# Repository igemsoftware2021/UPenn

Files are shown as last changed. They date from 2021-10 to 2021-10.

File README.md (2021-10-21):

# UPenn

OptoReader repository for software package to run the OptoReader, hardware files, and modeling scripts.

## Running the OptoReader

The OptoReader can be run using a computer and two Arduino Micros with the following provided code files: 

*OptoPlate_topArduino.ino* - Arduino code to control the stimulation plate. Takes in experiment stimulation settings, controls the 96 stimulation and optical density LEDs, and communicates with the reading plate for optical density measurements.

*PlateReader_bottomArduino.ino* - Arduino code to control the reading plate. Takes in experiment reading settings, controls the 96 excitation LEDs and photosensors, and communicates with the stimulation plate for optical density measurements. 

*OptoReader_Protocol.py* - Python code to take in inputs from the graphical user interface, keep track of experiment timing, and communicate with Arduinos to initiate readings and calibrate the optical density LEDs.

*GUI.py* - Python code creating a graphical user interface to take in user experiment inputs including stimulation settings, reading settings, feedback control, and experiment timing.

To run the OptoReader, first upload OptoPlate_topArduino.ino to the stimulation (top) plate Arduino and upload *PlateReader_bottomArduino.ino* to the reading (bottom) Arduino. Note the port name for each Arduino. If necessary, rename the port name from the preset COM11 and COM12 in *OptoReader_Protocol.py*. Finally, run GUI.py to open the graphical user interface and enter your experiment settings. Ensure that the image files *blue_logo.png* and *optologo_small.png* and the Python file *OptoReader_Protocol.py* are saved in the same folder as *GUI.py*.

## Hardware

### 3D Printed Parts
Includes files for our 3D-printed parts *Bottom_Adaptor.stl* and *Top_Adaptor.stl*. These files include the 3D model of the top adaptor and bottom adaptor, that fit each pcb board to a microwell plate.

### PCBs
Includes schematic files for our printed circuit boards (PCBs) *PlateReader.kicad_pcb* and *optoPlate96.kicad_pcb*. These can be sent directly to a company that provides printed circuit boards. The board components are soldered directly onto the boards. 

## Fluorescence Calibration Modeling

Files for our fluorescence calibration modeling include *FirstFit.m* and *Fluorescence_Calibration_Curve.m*. These files use our device’s fluorescence readings at different known concentrations to fit each well to a fluorescent calibration curve.

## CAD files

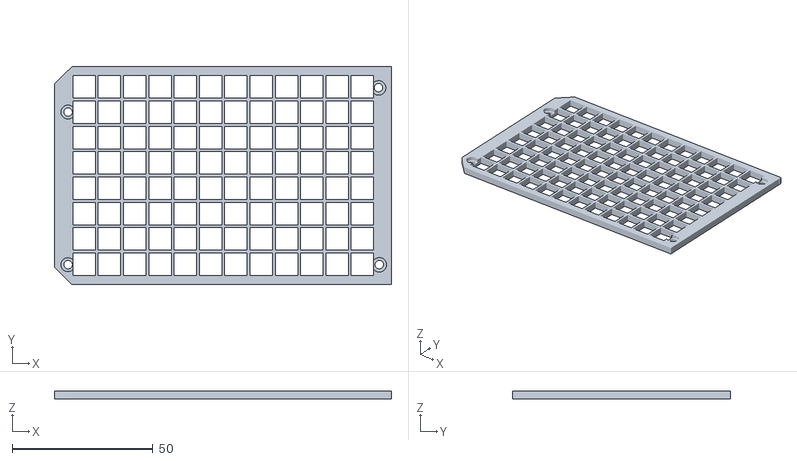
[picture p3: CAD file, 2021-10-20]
3D_Printed_Parts/Bottom_Adaptor.stl
119.9 x 77.6 x 3.00

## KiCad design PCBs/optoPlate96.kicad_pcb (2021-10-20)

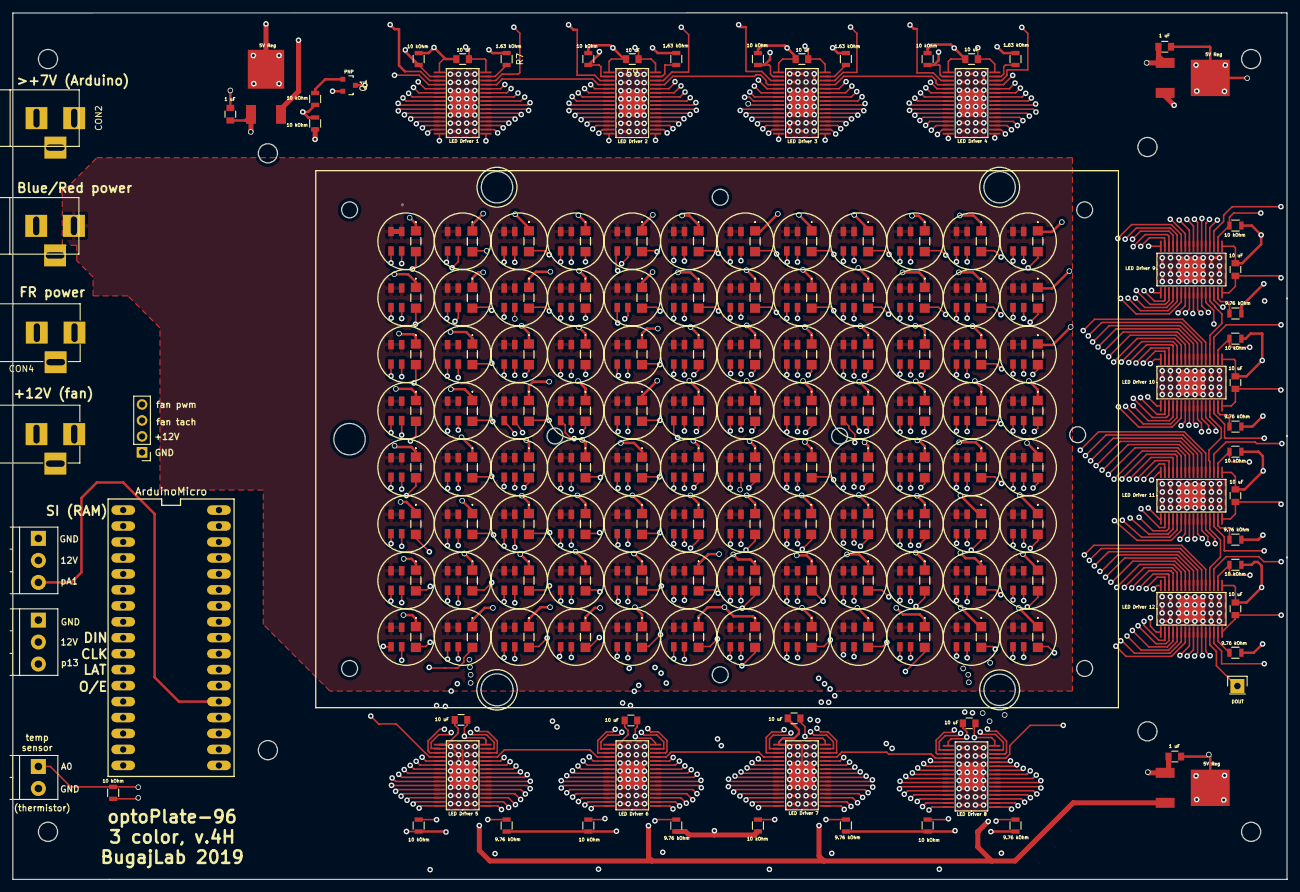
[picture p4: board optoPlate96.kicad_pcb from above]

Board: 6 copper layers, 202.8 x 137.9 mm, 260 parts (0 on the bottom side), 332 nets.

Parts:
C7, C8, C9, C10, C11, C12, C13, C14, C15, C16, C17, C18, C19, C25, C27: C; C_0805
CON1, CON2, CON3, CON4: BARREL_JACK
D3, D5, D7, D9, D11, D13, D15, D17, D19, D21, D23, D25, D27, D29, D31, D33, D35, D37, D39, D41, D43, D45, D47, D49, D51, D53, D55, D57, D59, D61, D63, D65, D67, D69, D71, D73, D75, D77, D79, D81, D83, D85, D87, D89, D91, D93, D95, D97, D99, D101, D103, D105, D107, D109, D111, D113, D115, D117, D119, D121, D123, D125, D127, D129, D131, D133, D135, D137, D139, D141, D143, D145, D147, D149, D151, D153, D155, D157, D159, D161, D163, D165, D167, D169, D171, D173, D175, D177, D179, D181, D183, D185, D187, D189, D191, D193: LED; HSMCC380
D4, D6, D8, D10, D12, D14, D16, D18, D20, D22, D24, D26, D28, D30, D32, D34, D36, D38, D40, D42, D44, D46, D48, D50, D52, D54, D56, D58, D60, D62, D64, D66, D68, D70, D72, D74, D76, D78, D80, D82, D84, D86, D88, D90, D92, D94, D96, D98, D100, D102, D104, D106, D108, D110, D112, D114, D116, D118, D120, D122, D124, D126, D128, D130, D132, D134, D136, D138, D140, D142, D144, D146, D148, D150, D152, D154, D156, D158, D160, D162, D164, D166, D168, D170, D172, D174, D176, D178, D180, D182, D184, D186, D188, D190, D192, D194: BI_LED; BiLED3528RedBlue
P2: CONN_01X01; Pin_Header_Straight_1x01
P3, P6: CONN_01X03; TerminalBlock_Pheonix_PT-3.5mm_3pol
P4: CONN_01X04; Pin_Header_Straight_1x04_Pitch2.54mm
P5: CONN_01X02; TerminalBlock_Pheonix_PT-3.5mm_2pol
Q1: PNP; PNP_SOT-23_correct
R1, R2, R3, R6, R7, R8, R9, R10, R11, R12, R13, R14, R15, R16, R17, R18, R19, R20, R21, R22, R23, R24, R25, R26, R27, R28, R29: R; R_0805
U1: ArduinoMicro; ArduinoMicro_DIP34
U4, U17, U18: LM2931AZ-5.0; Voltage_Regulator_LM2931ADT-5.0_noHoles
U5, U6, U7, U8, U9, U10, U11, U12, U13, U14, U15, U16: TLC5947; TLC5947_noHoles

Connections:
/3.3V: CON1.1, D4.1, D4.2, D6.1, D6.2, D8.1, D8.2, D10.1, D10.2, D12.1, D12.2, D14.1, D14.2, D16.1, D16.2, D18.1, D18.2, D20.1, D20.2, D22.1, D22.2, D24.1, D24.2, D26.1, D26.2, D28.1, D28.2, D30.1, D30.2, D32.1, D32.2, D34.1, D34.2, D36.1, D36.2, D38.1, D38.2, D40.1, D40.2, D42.1, D42.2, D44.1, D44.2, D46.1, D46.2, D48.1, D48.2, D50.1, D50.2, D52.1, D52.2, D54.1, D54.2, D56.1, D56.2, D58.1, D58.2, D60.1, D60.2, D62.1, D62.2, D64.1, D64.2, D66.1, D66.2, D68.1, D68.2, D70.1, D70.2, D72.1, D72.2, D74.1, D74.2, D76.1, D76.2, D78.1, D78.2, D80.1, D80.2, D82.1, D82.2, D84.1, D84.2, D86.1, D86.2, D88.1, D88.2, D90.1, D90.2, D92.1, D92.2, D94.1, D94.2, D96.1, D96.2, D98.1, D98.2, D100.1, D100.2, D102.1, D102.2, D104.1, D104.2, D106.1, D106.2, D108.1, D108.2, D110.1, D110.2, D112.1, D112.2, D114.1, D114.2, D116.1, D116.2, D118.1, D118.2, D120.1, D120.2, D122.1, D122.2, D124.1, D124.2, D126.1, D126.2, D128.1, D128.2, D130.1, D130.2, D132.1, D132.2, D134.1, D134.2, D136.1, D136.2, D138.1, D138.2, D140.1, D140.2, D142.1, D142.2, D144.1, D144.2, D146.1, D146.2, D148.1, D148.2, D150.1, D150.2, D152.1, D152.2, D154.1, D154.2, D156.1, D156.2, D158.1, D158.2, D160.1, D160.2, D162.1, D162.2, D164.1, D164.2, D166.1, D166.2, D168.1, D168.2, D170.1, D170.2, D172.1, D172.2, D174.1, D174.2, D176.1, D176.2, D178.1, D178.2, D180.1, D180.2, D182.1, D182.2, D184.1, D184.2, D186.1, D186.2, D188.1, D188.2, D190.1, D190.2, D192.1, D192.2, D194.1, D194.2
/3.3Vreal: R3.2, U1.19, U1.20
/5V: C13.1, C25.1, C27.1, CON2.1, U1.32, U4.3, U17.3, U18.3
/+12V: CON3.1, P3.2, P4.2, P6.2
/B1: D4.4, U5.5
/B2: D6.4, U5.6
/B3: D8.4, U5.7
/B4: D10.4, U5.8
/B5: D12.4, U5.9
/B6: D14.4, U5.10
/B7: D16.4, U5.11
/B8: D18.4, U5.12
/B9: D20.4, U5.13
/B10: D22.4, U5.14
/B11: D24.4, U5.15
/B12: D26.4, U5.16
/B13: D28.4, U5.17
/B14: D30.4, U5.18
/B15: D32.4, U5.19
/B16: D34.4, U5.20
/B17: D36.4, U5.21
/B18: D38.4, U5.22
/B19: D40.4, U5.23
/B20: D42.4, U5.24
/B21: D44.4, U5.25
/B22: D46.4, U5.26
/B23: D48.4, U5.27
/B24: D50.4, U5.28
/B25: D52.4, U6.5
/B26: D54.4, U6.6
/B27: D56.4, U6.7
/B28: D58.4, U6.8
/B29: D60.4, U6.9
/B30: D62.4, U6.10
/B31: D64.4, U6.11
/B32: D66.4, U6.12
/B33: D68.4, U6.13
/B34: D70.4, U6.14
/B35: D72.4, U6.15
/B36: D74.4, U6.16
/B37: D76.4, U6.17
/B38: D78.4, U6.18
/B39: D80.4, U6.19
/B40: D82.4, U6.20
/B41: D84.4, U6.21
/B42: D86.4, U6.22
/B43: D88.4, U6.23
/B44: D90.4, U6.24
/B45: D92.4, U6.25
/B46: D94.4, U6.26
/B47: D96.4, U6.27
/B48: D98.4, U6.28
/B49: D100.4, U7.5
/B50: D102.4, U7.6
/B51: D104.4, U7.7
/B52: D106.4, U7.8
/B53: D108.4, U7.9
/B54: D110.4, U7.10
/B55: D112.4, U7.11
/B56: D114.4, U7.12
/B57: D116.4, U7.13
/B58: D118.4, U7.14
/B59: D120.4, U7.15
/B60: D122.4, U7.16
/B61: D124.4, U7.17
/B62: D126.4, U7.18
/B63: D128.4, U7.19
/B64: D130.4, U7.20
/B65: D132.4, U7.21
/B66: D134.4, U7.22
/B67: D136.4, U7.23
/B68: D138.4, U7.24
/B69: D140.4, U7.25
/B70: D142.4, U7.26
/B71: D144.4, U7.27
/B72: D146.4, U7.28
/B73: D148.4, U8.5
/B74: D150.4, U8.6
/B75: D152.4, U8.7
/B76: D154.4, U8.8
/B77: D156.4, U8.9
/B78: D158.4, U8.10
/B79: D160.4, U8.11
/B80: D162.4, U8.12
/B81: D164.4, U8.13
/B82: D166.4, U8.14
/B83: D168.4, U8.15
/B84: D170.4, U8.16
/B85: D172.4, U8.17
/B86: D174.4, U8.18
/B87: D176.4, U8.19
/B88: D178.4, U8.20
/B89: D180.4, U8.21
/B90: D182.4, U8.22
/B91: D184.4, U8.23
/B92: D186.4, U8.24
/B93: D188.4, U8.25
/B94: D190.4, U8.26
/B95: D192.4, U8.27
/B96: D194.4, U8.28
/BLANK: Q1.3, R6.2, R8.2, R10.2, R12.2, R14.2, R16.2, R18.2, R20.2, R22.2, R24.2, R26.2, R28.2, U5.2, U6.2, U7.2, U8.2, U9.2, U10.2, U11.2, U12.2, U13.2, U14.2, U15.2, U16.2
/CLK: U1.10, U5.3, U6.3, U7.3, U8.3, U9.3, U10.3, U11.3, U12.3, U13.3, U14.3, U15.3, U16.3
/DIN: U1.9, U5.4
/DOUT: P2.1, U16.29
/FR1: D3.2, U13.5
/FR2: D5.2, U13.17
/FR3: D7.2, U14.5
/FR4: D9.2, U14.17
/FR5: D11.2, U15.5
/FR6: D13.2, U15.17
/FR7: D15.2, U16.5
/FR8: D17.2, U16.17
/FR9: D19.2, U13.6
/FR10: D21.2, U13.18
/FR11: D23.2, U14.6
/FR12: D25.2, U14.18
/FR13: D27.2, U15.6
/FR14: D29.2, U15.18
/FR15: D31.2, U16.6
/FR16: D33.2, U16.18
/FR17: D35.2, U13.7
/FR18: D37.2, U13.19
/FR19: D39.2, U14.7
/FR20: D41.2, U14.19
/FR21: D43.2, U15.7
/FR22: D45.2, U15.19
/FR23: D47.2, U16.7
/FR24: D49.2, U16.19
/FR25: D51.2, U13.8
/FR26: D53.2, U13.20
/FR27: D55.2, U14.8
/FR28: D57.2, U14.20
/FR29: D59.2, U15.8
/FR30: D61.2, U15.20
/FR31: D63.2, U16.8
/FR32: D65.2, U16.20
/FR33: D67.2, U13.9
/FR34: D69.2, U13.21
/FR35: D71.2, U14.9
/FR36: D73.2, U14.21
/FR37: D75.2, U15.9
/FR38: D77.2, U15.21
/FR39: D79.2, U16.9
/FR40: D81.2, U16.21
/FR41: D83.2, U13.10
/FR42: D85.2, U13.22
/FR43: D87.2, U14.10
/FR44: D89.2, U14.22
/FR45: D91.2, U15.10
/FR46: D93.2, U15.22
/FR47: D95.2, U16.10
/FR48: D97.2, U16.22
/FR49: D99.2, U13.11
/FR50: D101.2, U13.23
/FR51: D103.2, U14.11
/FR52: D105.2, U14.23
/FR53: D107.2, U15.11
/FR54: D109.2, U15.23
/FR55: D111.2, U16.11
/FR56: D113.2, U16.23
/FR57: D115.2, U13.12
/FR58: D117.2, U13.24
/FR59: D119.2, U14.12
/FR60: D121.2, U14.24
/FR61: D123.2, U15.12
/FR62: D125.2, U15.24
/FR63: D127.2, U16.12
/FR64: D129.2, U16.24
/FR65: D131.2, U13.13
/FR66: D133.2, U13.25
/FR67: D135.2, U14.13
/FR68: D137.2, U14.25
/FR69: D139.2, U15.13
/FR70: D141.2, U15.25
/FR71: D143.2, U16.13
/FR72: D145.2, U16.25
/FR73: D147.2, U13.14
/FR74: D149.2, U13.26
/FR75: D151.2, U14.14
/FR76: D153.2, U14.26
/FR77: D155.2, U15.14
/FR78: D157.2, U15.26
/FR79: D159.2, U16.14
/FR80: D161.2, U16.26
/FR81: D163.2, U13.15
/FR82: D165.2, U13.27
/FR83: D167.2, U14.15
/FR84: D169.2, U14.27
/FR85: D171.2, U15.15
/FR86: D173.2, U15.27
/FR87: D175.2, U16.15
/FR88: D177.2, U16.27
/FR89: D179.2, U13.16
/FR90: D181.2, U13.28
/FR91: D183.2, U14.16
/FR92: D185.2, U14.28
/FR93: D187.2, U15.16
/FR94: D189.2, U15.28
/FR95: D191.2, U16.16
/FR96: D193.2, U16.28
/LAT: U1.11, U5.30, U6.30, U7.30, U8.30, U9.30, U10.30, U11.30, U12.30, U13.30, U14.30, U15.30, U16.30
/R1: D4.3, U9.5
/R2: D6.3, U9.6
/R3: D8.3, U9.7
/R4: D10.3, U9.8
/R5: D12.3, U9.9
/R6: D14.3, U9.10
/R7: D16.3, U9.11
/R8: D18.3, U9.12
/R9: D20.3, U9.13
/R10: D22.3, U9.14
/R11: D24.3, U9.15
/R12: D26.3, U9.16
/R13: D28.3, U9.17
/R14: D30.3, U9.18
/R15: D32.3, U9.19
/R16: D34.3, U9.20
/R17: D36.3, U9.21
/R18: D38.3, U9.22
/R19: D40.3, U9.23
/R20: D42.3, U9.24
/R21: D44.3, U9.25
/R22: D46.3, U9.26
/R23: D48.3, U9.27
/R24: D50.3, U9.28
/R25: D52.3, U10.5
/R26: D54.3, U10.6
/R27: D56.3, U10.7
/R28: D58.3, U10.8
/R29: D60.3, U10.9
/R30: D62.3, U10.10
/R31: D64.3, U10.11
/R32: D66.3, U10.12
/R33: D68.3, U10.13
/R34: D70.3, U10.14
/R35: D72.3, U10.15
/R36: D74.3, U10.16
/R37: D76.3, U10.17
/R38: D78.3, U10.18
/R39: D80.3, U10.19
/R40: D82.3, U10.20
/R41: D84.3, U10.21
/R42: D86.3, U10.22
/R43: D88.3, U10.23
/R44: D90.3, U10.24
/R45: D92.3, U10.25
/R46: D94.3, U10.26
/R47: D96.3, U10.27
/R48: D98.3, U10.28
/R49: D100.3, U11.5
/R50: D102.3, U11.6
/R51: D104.3, U11.7
/R52: D106.3, U11.8
/R53: D108.3, U11.9
/R54: D110.3, U11.10
/R55: D112.3, U11.11
/R56: D114.3, U11.12
/R57: D116.3, U11.13
/R58: D118.3, U11.14
/R59: D120.3, U11.15
/R60: D122.3, U11.16
/R61: D124.3, U11.17
/R62: D126.3, U11.18
/R63: D128.3, U11.19
/R64: D130.3, U11.20
/R65: D132.3, U11.21
/R66: D134.3, U11.22
/R67: D136.3, U11.23
/R68: D138.3, U11.24
/R69: D140.3, U11.25
/R70: D142.3, U11.26
/R71: D144.3, U11.27
/R72: D146.3, U11.28
/R73: D148.3, U12.5
/R74: D150.3, U12.6
/R75: D152.3, U12.7
/R76: D154.3, U12.8
/R77: D156.3, U12.9
/R78: D158.3, U12.10
/R79: D160.3, U12.11
/R80: D162.3, U12.12
/R81: D164.3, U12.13
/R82: D166.3, U12.14
/R83: D168.3, U12.15
/R84: D170.3, U12.16
/R85: D172.3, U12.17
/R86: D174.3, U12.18
/R87: D176.3, U12.19
/R88: D178.3, U12.20
/R89: D180.3, U12.21
/R90: D182.3, U12.22
/R91: D184.3, U12.23
/R92: D186.3, U12.24
/R93: D188.3, U12.25
/R94: D190.3, U12.26
/R95: D192.3, U12.27
/R96: D194.3, U12.28
/Vfr: CON4.1, D3.1, D5.1, D7.1, D9.1, D11.1, D13.1, D15.1, D17.1, D19.1, D21.1, D23.1, D25.1, D27.1, D29.1, D31.1, D33.1, D35.1, D37.1, D39.1, D41.1, D43.1, D45.1, D47.1, D49.1, D51.1, D53.1, D55.1, D57.1, D59.1, D61.1, D63.1, D65.1, D67.1, D69.1, D71.1, D73.1, D75.1, D77.1, D79.1, D81.1, D83.1, D85.1, D87.1, D89.1, D91.1, D93.1, D95.1, D97.1, D99.1, D101.1, D103.1, D105.1, D107.1, D109.1, D111.1, D113.1, D115.1, D117.1, D119.1, D121.1, D123.1, D125.1, D127.1, D129.1, D131.1, D133.1, D135.1, D137.1, D139.1, D141.1, D143.1, D145.1, D147.1, D149.1, D151.1, D153.1, D155.1, D157.1, D159.1, D161.1, D163.1, D165.1, D167.1, D169.1, D171.1, D173.1, D175.1, D177.1, D179.1, D181.1, D183.1, D185.1, D187.1, D189.1, D191.1, D193.1
/aux_pwm1: P3.3, U1.18
/aux_pwm2: P6.3, U1.22
/fan_pwm: P4.4, U1.16
/fan_sense: P4.3, U1.15
/tempSense: P5.1, R3.1, U1.21
GND: C7.2, C8.2, C9.2, C10.2, C11.2, C12.2, C13.2, C14.2, C15.2, C16.2, C17.2, C18.2, C19.2, C25.2, C27.2, CON1.2, CON1.3, CON2.2, CON2.3, CON3.2, CON3.3, CON4.2, CON4.3, P3.1, P4.1, P5.2, P6.1, R1.1, R6.1, R7.1, R8.1, R9.1, R10.1, R11.1, R12.1, R13.1, R14.1, R15.1, R16.1, R17.1, R18.1, R19.1, R20.1, R21.1, R22.1, R23.1, R24.1, R25.1, R26.1, R27.1, R28.1, R29.1, U1.6, U1.31, U4.2, U5.1, U6.1, U7.1, U8.1, U9.1, U10.1, U11.1, U12.1, U13.1, U14.1, U15.1, U16.1, U17.2, U18.2
unnamed: C7.1, C10.1, C15.1, C16.1, U9.32, U10.32, U11.32, U12.32, U18.1
unnamed: C8.1, C9.1, C11.1, C12.1, Q1.1, U4.1, U5.32, U6.32, U7.32, U8.32
unnamed: C14.1, C17.1, C18.1, C19.1, U13.32, U14.32, U15.32, U16.32, U17.1
unnamed: Q1.2, R2.2
unnamed: R1.2, R2.1, U1.12
unnamed: R7.2, U5.31
unnamed: R9.2, U6.31
unnamed: R11.2, U7.31
unnamed: R13.2, U8.31
unnamed: R15.2, U9.31
unnamed: R17.2, U10.31
unnamed: R19.2, U11.31
unnamed: R21.2, U12.31
unnamed: R23.2, U13.31
unnamed: R25.2, U14.31
unnamed: R27.2, U15.31
unnamed: R29.2, U16.31
unnamed: U5.29, U6.4
unnamed: U6.29, U7.4
unnamed: U7.29, U8.4
unnamed: U8.29, U9.4
unnamed: U9.29, U10.4
unnamed: U10.29, U11.4
unnamed: U11.29, U12.4
unnamed: U12.29, U13.4
unnamed: U13.29, U14.4
unnamed: U14.29, U15.4
unnamed: U15.29, U16.4

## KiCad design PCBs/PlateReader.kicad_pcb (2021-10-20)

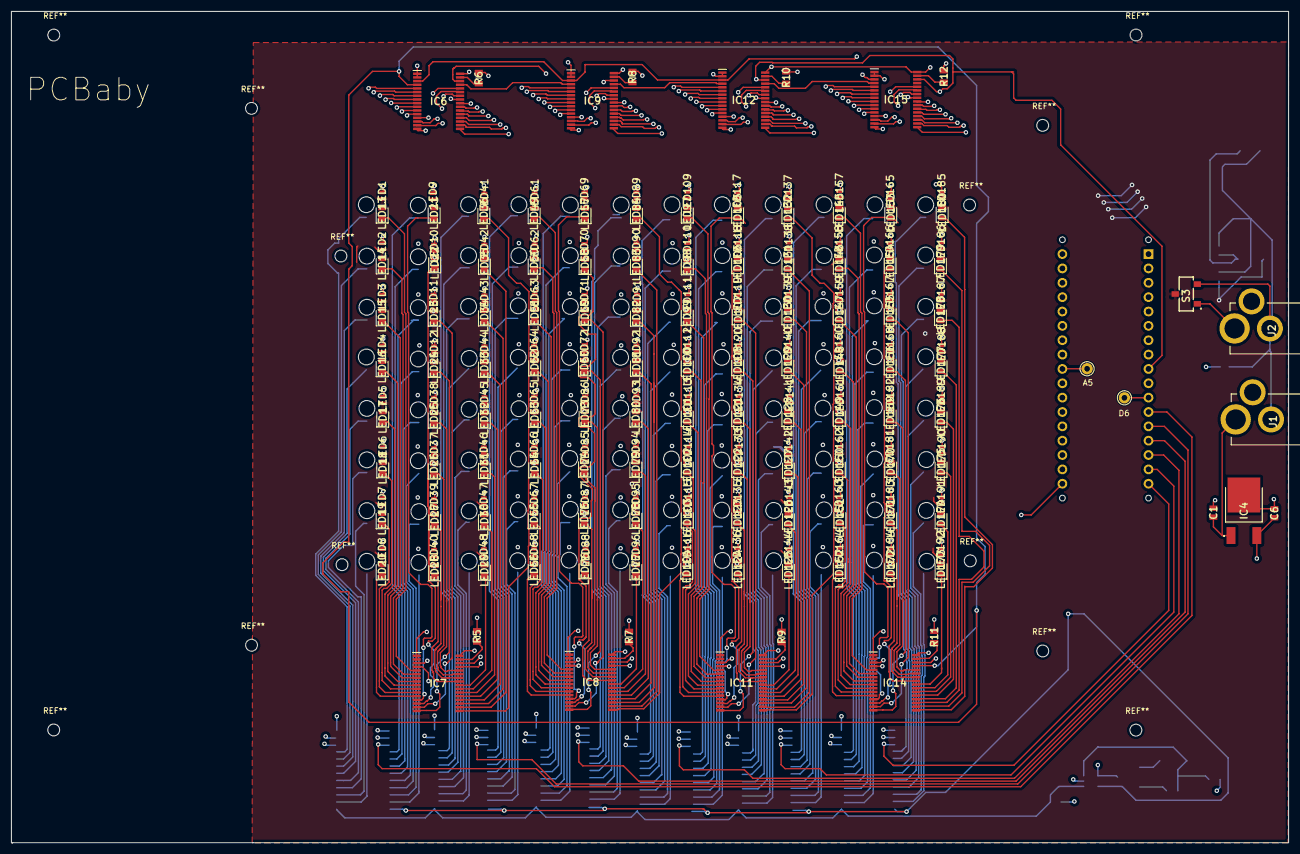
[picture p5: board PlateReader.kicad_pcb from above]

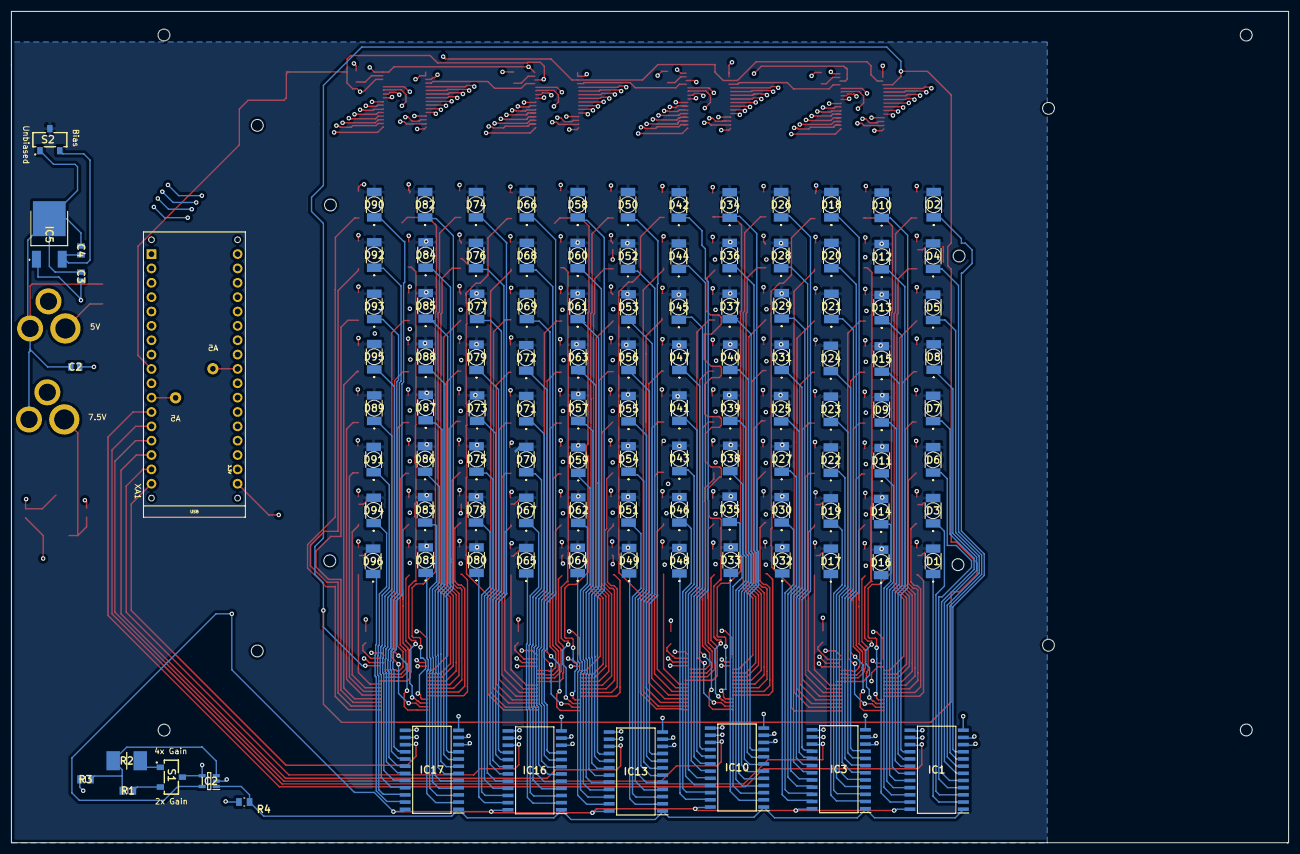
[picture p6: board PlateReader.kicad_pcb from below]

Board: 4 copper layers, 226.0 x 147.1 mm, 330 parts (114 on the bottom side), 328 nets.

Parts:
A5, A5#2: Pin_D1.0mm_L10.0mm
C1, C2, C3, C4: UMK212B7105KG-T; CAPC2012X135N
C6: GMK212BBJ106KG-T; CAPC2012X135N
D1, D2, D3, D4, D5, D6, D7, D8, D9, D10, D11, D12, D13, D14, D15, D16, D17, D18, D19, D20, D21, D22, D23, D24, D25, D26, D27, D28, D29, D30, D31, D32, D33, D34, D35, D36, D37, D38, D39, D40, D41, D42, D43, D44, D45, D46, D47, D48, D49, D50, D51, D52, D53, D54, D55, D56, D57, D58, D59, D60, D61, D62, D63, D64, D65, D66, D67, D68, D69, D70, D71, D72, D73, D74, D75, D76, D77, D78, D79, D80, D81, D82, D83, D84, D85, D86, D87, D88, D89, D90, D91, D92, D93, D94, D95, D96: SFH_2270R; SFH2270R
IC1, IC3, IC10, IC13, IC16, IC17: CD74HCT4067M; SOIC127P1030X265-24N
IC2: NCV321SN3T1G; SOT95P275X110-5N
IC4, IC5: NCP5501DT15RKG; NCP5501DT50RKG
IC6, IC7, IC8, IC9, IC11, IC12, IC14, IC15: TLC5947DAP; SOP65P810X120-33N
J1, J2: RAPC722X
LED1, LED2, LED3, LED4, LED5, LED6, LED7, LED8, LED9, LED10, LED11, LED12, LED37, LED38, LED39, LED40, LED41, LED42, LED43, LED44, LED45, LED46, LED47, LED48, LED61, LED62, LED63, LED64, LED65, LED66, LED67, LED68, LED69, LED70, LED71, LED72, LED85, LED86, LED87, LED88, LED89, LED90, LED91, LED92, LED93, LED94, LED95, LED96, LED109, LED110, LED111, LED112, LED113, LED114, LED115, LED116, LED117, LED118, LED119, LED120, LED133, LED134, LED135, LED136, LED137, LED138, LED139, LED140, LED141, LED142, LED143, LED144, LED157, LED158, LED159, LED160, LED161, LED162, LED163, LED164, LED165, LED166, LED167, LED168, LED181, LED182, LED183, LED184, LED185, LED186, LED187, LED188, LED189, LED190, LED191, LED192: ATS2012UV395
LED13, LED14, LED15, LED16, LED17, LED18, LED19, LED20, LED21, LED22, LED23, LED24, LED25, LED26, LED27, LED28, LED29, LED30, LED31, LED32, LED33, LED34, LED35, LED36, LED49, LED50, LED51, LED52, LED53, LED54, LED55, LED56, LED57, LED58, LED59, LED60, LED73, LED74, LED75, LED76, LED77, LED78, LED79, LED80, LED81, LED82, LED83, LED84, LED97, LED98, LED99, LED100, LED101, LED102, LED103, LED104, LED105, LED106, LED107, LED108, LED121, LED122, LED123, LED124, LED125, LED126, LED127, LED128, LED129, LED130, LED131, LED132, LED145, LED146, LED147, LED148, LED149, LED150, LED151, LED152, LED153, LED154, LED155, LED156, LED169, LED170, LED171, LED172, LED173, LED174, LED175, LED176, LED177, LED178, LED179, LED180: 155060BS75300; LEDC2012X85N
R1, R3: RC0805JR-07130RL; RESC2012X60N
R2: CRGH2512J390R; RESC6432X65N
R4: CRCW080550M0JPEAHR; RESC2013X65N
R5, R6, R7, R8, R9, R10, R11, R12: RN732ATTD1651B25; RESC2012X60N
S1, S2, S3: CJS-1200TB; B-TYPE
XA1: Arduino_Micro_Socket

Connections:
+5V: C3.2, IC5.1, LED1.2, LED2.2, LED3.2, LED4.2, LED5.2, LED6.2, LED7.2, LED8.2, LED9.2, LED10.2, LED11.2, LED12.2, LED13.2, LED14.2, LED15.2, LED16.2, LED17.2, LED18.2, LED19.2, LED20.2, LED21.2, LED22.2, LED23.2, LED24.2, LED25.2, LED26.2, LED27.2, LED28.2, LED29.2, LED30.2, LED31.2, LED32.2, LED33.2, LED34.2, LED35.2, LED36.2, LED37.2, LED38.2, LED39.2, LED40.2, LED41.2, LED42.2, LED43.2, LED44.2, LED45.2, LED46.2, LED47.2, LED48.2, LED49.2, LED50.2, LED51.2, LED52.2, LED53.2, LED54.2, LED55.2, LED56.2, LED57.2, LED58.2, LED59.2, LED60.2, LED61.2, LED62.2, LED63.2, LED64.2, LED65.2, LED66.2, LED67.2, LED68.2, LED69.2, LED70.2, LED71.2, LED72.2, LED73.2, LED74.2, LED75.2, LED76.2, LED77.2, LED78.2, LED79.2, LED80.2, LED81.2, LED82.2, LED83.2, LED84.2, LED85.2, LED86.2, LED87.2, LED88.2, LED89.2, LED90.2, LED91.2, LED92.2, LED93.2, LED94.2, LED95.2, LED96.2, LED97.2, LED98.2, LED99.2, LED100.2, LED101.2, LED102.2, LED103.2, LED104.2, LED105.2, LED106.2, LED107.2, LED108.2, LED109.2, LED110.2, LED111.2, LED112.2, LED113.2, LED114.2, LED115.2, LED116.2, LED117.2, LED118.2, LED119.2, LED120.2, LED121.2, LED122.2, LED123.2, LED124.2, LED125.2, LED126.2, LED127.2, LED128.2, LED129.2, LED130.2, LED131.2, LED132.2, LED133.2, LED134.2, LED135.2, LED136.2, LED137.2, LED138.2, LED139.2, LED140.2, LED141.2, LED142.2, LED143.2, LED144.2, LED145.2, LED146.2, LED147.2, LED148.2, LED149.2, LED150.2, LED151.2, LED152.2, LED153.2, LED154.2, LED155.2, LED156.2, LED157.2, LED158.2, LED159.2, LED160.2, LED161.2, LED162.2, LED163.2, LED164.2, LED165.2, LED166.2, LED167.2, LED168.2, LED169.2, LED170.2, LED171.2, LED172.2, LED173.2, LED174.2, LED175.2, LED176.2, LED177.2, LED178.2, LED179.2, LED180.2, LED181.2, LED182.2, LED183.2, LED184.2, LED185.2, LED186.2, LED187.2, LED188.2, LED189.2, LED190.2, LED191.2, LED192.2, S3.2
+7.5V: C1.2, IC4.1, J1.3
GND: C1.1, C2.1, C3.1, C4.1, C6.1, IC1.12, IC2.2, IC3.12, IC4.2, IC5.2, IC6.1, IC6.2, IC7.1, IC7.2, IC8.1, IC8.2, IC9.1, IC9.2, IC10.12, IC11.1, IC11.2, IC12.1, IC12.2, IC13.12, IC14.1, IC14.2, IC15.1, IC15.2, IC16.12, IC17.12, J1.2, J2.2, R3.2, R4.2, R5.1, R6.1, R7.1, R8.1, R9.1, R10.1, R11.1, R12.1, S2.1, S3.3, XA1.GND1
unnamed: C2.2, C6.2, IC1.24, IC2.5, IC3.24, IC4.3, IC6.32, IC7.32, IC8.32, IC9.32, IC10.24, IC11.32, IC12.32, IC13.24, IC14.32, IC15.32, IC16.24, IC17.24
unnamed: C4.2, IC5.3, S2.3
unnamed: D1.1, IC1.2
unnamed: D1.2, D2.2, D3.2, D4.2, D5.2, D6.2, D7.2, D8.2, D9.2, D10.2, D11.2, D12.2, D13.2, D14.2, D15.2, D16.2, D17.2, D18.2, D19.2, D20.2, D21.2, D22.2, D23.2, D24.2, D25.2, D26.2, D27.2, D28.2, D29.2, D30.2, D31.2, D32.2, D33.2, D34.2, D35.2, D36.2, D37.2, D38.2, D39.2, D40.2, D41.2, D42.2, D43.2, D44.2, D45.2, D46.2, D47.2, D48.2, D49.2, D50.2, D51.2, D52.2, D53.2, D54.2, D55.2, D56.2, D57.2, D58.2, D59.2, D60.2, D61.2, D62.2, D63.2, D64.2, D65.2, D66.2, D67.2, D68.2, D69.2, D70.2, D71.2, D72.2, D73.2, D74.2, D75.2, D76.2, D77.2, D78.2, D79.2, D80.2, D81.2, D82.2, D83.2, D84.2, D85.2, D86.2, D87.2, D88.2, D89.2, D90.2, D91.2, D92.2, D93.2, D94.2, D95.2, D96.2, S2.2
unnamed: D2.1, IC1.9
unnamed: D3.1, IC1.3
unnamed: D4.1, IC1.8
unnamed: D5.1, IC1.7
unnamed: D6.1, IC1.4
unnamed: D7.1, IC1.5
unnamed: D8.1, IC1.6
unnamed: D9.1, IC1.20
unnamed: D10.1, IC1.16
unnamed: D11.1, IC1.21
unnamed: D12.1, IC1.17
unnamed: D13.1, IC1.18
unnamed: D14.1, IC1.22
unnamed: D15.1, IC1.19
unnamed: D16.1, IC1.23
unnamed: D17.1, IC3.2
unnamed: D18.1, IC3.9
unnamed: D19.1, IC3.3
unnamed: D20.1, IC3.8
unnamed: D21.1, IC3.7
unnamed: D22.1, IC3.4
unnamed: D23.1, IC3.5
unnamed: D24.1, IC3.6
unnamed: D25.1, IC3.20
unnamed: D26.1, IC3.16
unnamed: D27.1, IC3.21
unnamed: D28.1, IC3.17
unnamed: D29.1, IC3.18
unnamed: D30.1, IC3.22
unnamed: D31.1, IC3.19
unnamed: D32.1, IC3.23
unnamed: D33.1, IC10.2
unnamed: D34.1, IC10.9
unnamed: D35.1, IC10.3
unnamed: D36.1, IC10.8
unnamed: D37.1, IC10.7
unnamed: D38.1, IC10.4
unnamed: D39.1, IC10.5
unnamed: D40.1, IC10.6
unnamed: D41.1, IC10.20
unnamed: D42.1, IC10.16
unnamed: D43.1, IC10.21
unnamed: D44.1, IC10.17
unnamed: D45.1, IC10.18
unnamed: D46.1, IC10.22
unnamed: D47.1, IC10.19
unnamed: D48.1, IC10.23
unnamed: D49.1, IC13.2
unnamed: D50.1, IC13.9
unnamed: D51.1, IC13.3
unnamed: D52.1, IC13.8
unnamed: D53.1, IC13.7
unnamed: D54.1, IC13.4
unnamed: D55.1, IC13.5
unnamed: D56.1, IC13.6
unnamed: D57.1, IC13.20
unnamed: D58.1, IC13.16
unnamed: D59.1, IC13.21
unnamed: D60.1, IC13.17
unnamed: D61.1, IC13.18
unnamed: D62.1, IC13.22
unnamed: D63.1, IC13.19
unnamed: D64.1, IC13.23
unnamed: D65.1, IC16.2
unnamed: D66.1, IC16.9
unnamed: D67.1, IC16.3
unnamed: D68.1, IC16.8
unnamed: D69.1, IC16.7
unnamed: D70.1, IC16.4
unnamed: D71.1, IC16.5
unnamed: D72.1, IC16.6
unnamed: D73.1, IC16.20
unnamed: D74.1, IC16.16
unnamed: D75.1, IC16.21
unnamed: D76.1, IC16.17
unnamed: D77.1, IC16.18
unnamed: D78.1, IC16.22
unnamed: D79.1, IC16.19
unnamed: D80.1, IC16.23
unnamed: D81.1, IC17.2
unnamed: D82.1, IC17.9
unnamed: D83.1, IC17.3
unnamed: D84.1, IC17.8
unnamed: D85.1, IC17.7
unnamed: D86.1, IC17.4
unnamed: D87.1, IC17.5
unnamed: D88.1, IC17.6
unnamed: D89.1, IC17.20
unnamed: D90.1, IC17.16
unnamed: D91.1, IC17.21
unnamed: D92.1, IC17.17
unnamed: D93.1, IC17.18
unnamed: D94.1, IC17.22
unnamed: D95.1, IC17.19
unnamed: D96.1, IC17.23
unnamed: IC1.1, IC2.1, IC3.1, IC10.1, IC13.1, IC16.1, IC17.1, R4.1
unnamed: IC1.10, IC3.10, IC10.10, IC13.10, IC16.10, IC17.10, XA1.A1
unnamed: IC1.11, IC3.11, IC10.11, IC13.11, IC16.11, IC17.11, XA1.A2
unnamed: IC1.13, IC3.13, IC10.13, IC13.13, IC16.13, IC17.13, XA1.A4
unnamed: IC1.14, IC3.14, IC10.14, IC13.14, IC16.14, IC17.14, XA1.A3
unnamed: IC1.15, XA1.D7
unnamed: IC2.3, R1.2, R2.2, R3.1
unnamed: IC2.4, S1.2, XA1.A0
unnamed: IC3.15, XA1.D8
unnamed: IC6.5, LED1.1
unnamed: IC6.6, LED2.1
unnamed: IC6.7, LED3.1
unnamed: IC6.8, LED4.1
unnamed: IC6.9, LED5.1
unnamed: IC6.10, LED6.1
unnamed: IC6.11, LED7.1
unnamed: IC6.12, LED8.1
unnamed: IC6.13, LED9.1
unnamed: IC6.14, LED10.1
unnamed: IC6.15, LED11.1
unnamed: IC6.16, LED12.1
unnamed: IC6.17, LED48.1
unnamed: IC6.18, LED47.1
unnamed: IC6.19, LED46.1
unnamed: IC6.20, LED45.1
unnamed: IC6.21, LED44.1
unnamed: IC6.22, LED43.1
unnamed: IC6.23, LED42.1
unnamed: IC6.24, LED41.1
unnamed: IC6.25, LED40.1
unnamed: IC6.26, LED39.1
unnamed: IC6.27, LED38.1
unnamed: IC6.28, LED37.1
unnamed: IC6.29, IC9.4
unnamed: IC6.31, R6.2
unnamed: IC7.4, XA1.D13
unnamed: IC7.5, LED13.1
unnamed: IC7.6, LED14.1
unnamed: IC7.7, LED15.1
unnamed: IC7.8, LED16.1
unnamed: IC7.9, LED17.1
unnamed: IC7.10, LED18.1
unnamed: IC7.11, LED19.1
unnamed: IC7.12, LED20.1
unnamed: IC7.13, LED21.1
unnamed: IC7.14, LED22.1
unnamed: IC7.15, LED23.1
unnamed: IC7.16, LED24.1
unnamed: IC7.17, LED36.1
unnamed: IC7.18, LED35.1
unnamed: IC7.19, LED34.1
unnamed: IC7.20, LED33.1
unnamed: IC7.21, LED32.1
unnamed: IC7.22, LED31.1
unnamed: IC7.23, LED30.1
unnamed: IC7.24, LED29.1
unnamed: IC7.25, LED28.1
unnamed: IC7.26, LED27.1
unnamed: IC7.27, LED26.1
unnamed: IC7.28, LED25.1
unnamed: IC7.29, IC8.4
unnamed: IC7.31, R5.2
unnamed: IC8.5, LED49.1
unnamed: IC8.6, LED50.1
unnamed: IC8.7, LED51.1
unnamed: IC8.8, LED52.1
unnamed: IC8.9, LED53.1
unnamed: IC8.10, LED54.1
unnamed: IC8.11, LED55.1
unnamed: IC8.12, LED56.1
unnamed: IC8.13, LED57.1
unnamed: IC8.14, LED58.1
unnamed: IC8.15, LED59.1
unnamed: IC8.16, LED60.1
unnamed: IC8.17, LED84.1
unnamed: IC8.18, LED83.1
unnamed: IC8.19, LED82.1
unnamed: IC8.20, LED81.1
unnamed: IC8.21, LED80.1
unnamed: IC8.22, LED79.1
unnamed: IC8.23, LED78.1
unnamed: IC8.24, LED77.1
unnamed: IC8.25, LED76.1
unnamed: IC8.26, LED75.1
unnamed: IC8.27, LED74.1
unnamed: IC8.28, LED73.1
unnamed: IC8.31, R7.2
unnamed: IC9.5, LED61.1
unnamed: IC9.6, LED62.1
unnamed: IC9.7, LED63.1
unnamed: IC9.8, LED64.1
unnamed: IC9.9, LED65.1
unnamed: IC9.10, LED66.1
unnamed: IC9.11, LED67.1
unnamed: IC9.12, LED68.1
unnamed: IC9.13, LED69.1
unnamed: IC9.14, LED70.1
unnamed: IC9.15, LED71.1
unnamed: IC9.16, LED72.1
unnamed: IC9.17, LED96.1
unnamed: IC9.18, LED95.1
unnamed: IC9.19, LED94.1
unnamed: IC9.20, LED93.1
unnamed: IC9.21, LED92.1
unnamed: IC9.22, LED91.1
unnamed: IC9.23, LED90.1
unnamed: IC9.24, LED89.1
unnamed: IC9.25, LED88.1
unnamed: IC9.26, LED87.1
unnamed: IC9.27, LED86.1
unnamed: IC9.28, LED85.1
unnamed: IC9.31, R8.2
unnamed: IC10.15, XA1.D9
unnamed: IC6.3, IC7.3, IC8.3, IC9.3, IC11.3, IC12.3, IC14.3, IC15.3, XA1.D5
unnamed: IC8.29, IC11.4
unnamed: IC11.5, LED97.1
unnamed: IC11.6, LED98.1
unnamed: IC11.7, LED99.1
unnamed: IC11.8, LED100.1
unnamed: IC11.9, LED101.1
unnamed: IC11.10, LED102.1
unnamed: IC11.11, LED103.1
unnamed: IC11.12, LED104.1
unnamed: IC11.13, LED105.1
unnamed: IC11.14, LED106.1
unnamed: IC11.15, LED107.1
unnamed: IC11.16, LED108.1
unnamed: IC11.17, LED132.1
unnamed: IC11.18, LED131.1
unnamed: IC11.19, LED130.1
unnamed: IC11.20, LED129.1
unnamed: IC11.21, LED128.1
unnamed: IC11.22, LED127.1
unnamed: IC11.23, LED126.1
unnamed: IC11.24, LED125.1
unnamed: IC11.25, LED124.1
unnamed: IC11.26, LED123.1
unnamed: IC11.27, LED122.1
unnamed: IC11.28, LED121.1
unnamed: IC11.29, IC14.4
unnamed: IC6.30, IC7.30, IC8.30, IC9.30, IC11.30, IC12.30, IC14.30, IC15.30, XA1.D4
unnamed: IC11.31, R9.2
unnamed: IC9.29, IC12.4
unnamed: IC12.5, LED109.1
unnamed: IC12.6, LED110.1
unnamed: IC12.7, LED111.1
unnamed: IC12.8, LED112.1
unnamed: IC12.9, LED113.1
unnamed: IC12.10, LED114.1
unnamed: IC12.11, LED115.1
unnamed: IC12.12, LED116.1
unnamed: IC12.13, LED117.1
unnamed: IC12.14, LED118.1
unnamed: IC12.15, LED119.1
unnamed: IC12.16, LED120.1
unnamed: IC12.17, LED144.1
unnamed: IC12.18, LED143.1
unnamed: IC12.19, LED142.1
unnamed: IC12.20, LED141.1
unnamed: IC12.21, LED140.1
unnamed: IC12.22, LED139.1
unnamed: IC12.23, LED138.1
unnamed: IC12.24, LED137.1
unnamed: IC12.25, LED136.1
unnamed: IC12.26, LED135.1
unnamed: IC12.27, LED134.1
unnamed: IC12.28, LED133.1
unnamed: IC12.29, IC15.4
unnamed: IC12.31, R10.2
unnamed: IC13.15, XA1.D10
unnamed: IC14.5, LED145.1
unnamed: IC14.6, LED146.1
unnamed: IC14.7, LED147.1
unnamed: IC14.8, LED148.1
unnamed: IC14.9, LED149.1
unnamed: IC14.10, LED150.1
unnamed: IC14.11, LED151.1
unnamed: IC14.12, LED152.1
unnamed: IC14.13, LED153.1
unnamed: IC14.14, LED154.1
unnamed: IC14.15, LED155.1
unnamed: IC14.16, LED156.1
unnamed: IC14.17, LED180.1
unnamed: IC14.18, LED179.1
unnamed: IC14.19, LED178.1
unnamed: IC14.20, LED177.1
unnamed: IC14.21, LED176.1
unnamed: IC14.22, LED175.1
unnamed: IC14.23, LED174.1
unnamed: IC14.24, LED173.1
unnamed: IC14.25, LED172.1
unnamed: IC14.26, LED171.1
unnamed: IC14.27, LED170.1
unnamed: IC14.28, LED169.1
unnamed: IC6.4, IC14.29
unnamed: IC14.31, R11.2
unnamed: IC15.5, LED157.1
unnamed: IC15.6, LED158.1
unnamed: IC15.7, LED159.1
unnamed: IC15.8, LED160.1
unnamed: IC15.9, LED161.1
unnamed: IC15.10, LED162.1
unnamed: IC15.11, LED163.1
unnamed: IC15.12, LED164.1
unnamed: IC15.13, LED165.1
unnamed: IC15.14, LED166.1
unnamed: IC15.15, LED167.1
unnamed: IC15.16, LED168.1
unnamed: IC15.17, LED192.1
unnamed: IC15.18, LED191.1
unnamed: IC15.19, LED190.1
unnamed: IC15.20, LED189.1
unnamed: IC15.21, LED188.1
unnamed: IC15.22, LED187.1
unnamed: IC15.23, LED186.1
unnamed: IC15.24, LED185.1
unnamed: IC15.25, LED184.1
unnamed: IC15.26, LED183.1
unnamed: IC15.27, LED182.1
unnamed: IC15.28, LED181.1
unnamed: IC15.31, R12.2
unnamed: IC16.15, XA1.D11
unnamed: IC17.15, XA1.D12
unnamed: J2.3, S3.1
unnamed: R1.1, S1.3
unnamed: R2.1, S1.1

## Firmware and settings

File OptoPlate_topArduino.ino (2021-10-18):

// OPTOPLATE 

// Driver setup
#include "Adafruit_TLC5947.h"

const uint8_t NUM_TLC5974 = 12; 
const uint8_t data  = 4;
const uint8_t clock = 5;
const uint8_t latch = 6;
const uint8_t enable  = 7;  // set to -1 to not use the enable pin (its optional)
int redint = 300;

const int chanNum = 24*NUM_TLC5974;

Adafruit_TLC5947 tlc = Adafruit_TLC5947(NUM_TLC5974, clock, data, latch); //creates LED driver object
// End of driver setup

// Define variables


int intensity[] = {0,0,0,0,0,0,0,0,0,0,0,0,
                   0,0,0,0,0,0,0,0,0,0,0,0,
                   0,0,0,0,0,0,0,0,0,0,0,0,
                   0,0,0,0,0,0,0,0,0,0,0,0,
                   0,0,0,0,0,0,0,0,0,0,0,0,
                   0,0,0,0,0,0,0,0,0,0,0,0,
                   0,0,0,0,0,0,0,0,0,0,0,0,
                   0,0,0,0,0,0,0,0,0,0,0,0}; //  blue LED intensity for wells 1-96

                   
int timeON[] = {0,0,0,0,0,0,0,0,0,0,0,0,
                0,0,0,0,0,0,0,0,0,0,0,0,
                0,0,0,0,0,0,0,0,0,0,0,0,
                 0,0,0,0,0,0,0,0,0,0,0,0,
                0,0,0,0,0,0,0,0,0,0,0,0,
                0,0,0,0,0,0,0,0,0,0,0,0,
                0,0,0,0,0,0,0,0,0,0,0,0,
                0,0,0,0,0,0,0,0,0,0,0,0};  //  blue LED time ON interval for wells 1-96
                
int timeOFF[] = {0,0,0,0,0,0,0,0,0,0,0,0,
                 0,0,0,0,0,0,0,0,0,0,0,0,
                 0,0,0,0,0,0,0,0,0,0,0,0,
                 0,0,0,0,0,0,0,0,0,0,0,0,
                 0,0,0,0,0,0,0,0,0,0,0,0,
                 0,0,0,0,0,0,0,0,0,0,0,0,
                 0,0,0,0,0,0,0,0,0,0,0,0,
                 0,0,0,0,0,0,0,0,0,0,0,0};  //  blue LED time OFF interval for wells 1-96



long previousMillisStim[] = {0,0,0,0,0,0,0,0,0,0,0,0,
                            0,0,0,0,0,0,0,0,0,0,0,0,
                            0,0,0,0,0,0,0,0,0,0,0,0,
                             0,0,0,0,0,0,0,0,0,0,0,0,
                            0,0,0,0,0,0,0,0,0,0,0,0,
                            0,0,0,0,0,0,0,0,0,0,0,0,
                            0,0,0,0,0,0,0,0,0,0,0,0,
                            0,0,0,0,0,0,0,0,0,0,0,0};  //  time at last stimulation for wells 1-96

int state[] = {0,0,0,0,0,0,0,0,0,0,0,0,
               0,0,0,0,0,0,0,0,0,0,0,0,
               0,0,0,0,0,0,0,0,0,0,0,0,
                0,0,0,0,0,0,0,0,0,0,0,0,
               0,0,0,0,0,0,0,0,0,0,0,0,
               0,0,0,0,0,0,0,0,0,0,0,0,
               0,0,0,0,0,0,0,0,0,0,0,0,
               0,0,0,0,0,0,0,0,0,0,0,0}; //  track whether blue LEDs are ON (1) or OFF (0) for wells 1-96
               
String protocol;
long currentMillis;
String all_wells;
int fpSwitch = 0;


void setup() {  
  
  //Driver setup
  pinMode(enable, OUTPUT);
  digitalWrite(enable, HIGH);
  tlc.begin();
  Serial.begin(9600);
  
  // Loop through all 96 wells (chanNum/3 = 96) and set to initial OFF (0) state
  
  for (uint16_t i = 0; i < chanNum/3; i++){
    setAll(i, 0);
  }
  tlc.write();
  tlc.write();
  
  // Set enable pin HIGH to turn on drivers if using 
  
  if (enable >= 0) {
    pinMode(enable, OUTPUT);
    digitalWrite(enable, HIGH);
  }
  
  while (Serial.available() == 0) {
    //Wait for connection
  }
    
  while (Serial.available() > 0) {
    Serial.read();
  }  
  
  while(Serial.available() == 0){
    //Wait
  }
  
  while (Serial.readStringUntil(';') != "S"){
    // wait
  }
  while (Serial.available() == 0) {
    //Wait for connection
  }
  
  // CALIBRATE RED LEDS
  
  String r = Serial.readStringUntil(';'); 
  if (r == "calibrate"){
    calibrate();
  }

  //  READ STIMULATION LED PROTOCOLS FROM PYTHON 
  
  all_wells = Serial.readStringUntil(';'); // string of 96 characters indicating which wells are in use via setting index to 1
  
  for (int i = 0; i < 96; i++) { // Take in blue LED-specific instructions 
    intensity[i] = Serial.readStringUntil(';').toInt(); // LED intensity
  }

  for (int i = 0; i < 96; i++) { // Take in blue LED-specific instructions 
    timeON[i] = Serial.readStringUntil(';').toInt(); // LED ON duration
  }

  for (int i = 0; i < 96; i++) { // Take in blue LED-specific instructions     
    timeOFF[i] = Serial.readStringUntil(';').toInt(); // LED OFF duration
  }
    

// Calibrating timer

  int startMillis = round(millis()/1000);
  for(int i = 0; i < 96; i++){
    previousMillisStim[i] == startMillis;
  }
}

void loop() {
  currentMillis = round(millis()/1000);
  
  protocol = Serial.readStringUntil(';'); // Constantly waiting to read from pi

  if (protocol == "O"){   //  OPTICAL DENSITY READING LOOP
    OpticalDensity();
  }

  if (protocol == "odoff"){   // TURN ALL RED LEDS OFF AND RESUME STIMULATION AFTER OD READING
    resumeStim_OD();
  }
  

  if (protocol == "blueoff"){   // TURN STIM LEDS OFF WHEN READING FLUORESCENCE
    Fluorescence();
  }

  if (protocol == "blueon"){   // RESUME STIMULATION AFTER FLUORESCENCE READING
    resumeStim_Fluor();
  }

  if (protocol == "new_stim"){ // BEGIN STIMULATION ON COMPUTER COMMAND
    new_stimulation();
  }
  
  if (protocol == "shutdown"){   // SHUTDOWN PLATE
    endComm();
  }

  //  *** STIMULATION LIGHT PROTOCOL ***
  
  // TURN BLUE LEDS ON
  for (int i = 0; i < 96; i++) {
    if (currentMillis - previousMillisStim[i] >= timeOFF[i]){ // checking timer
      if ((state[i] == 0) && (fpSwitch == 0)){ // checking if well is OFF and fluorescence reading is not occurring 
        setBlue(i, intensity[i]);  
        state[i] = 1; // indicates that well light is ON
        previousMillisStim[i] = currentMillis;  // resets timer
      }
    }
  }
  tlc.write();
       
  // TURN BLUE LEDS OFF
  for (int i = 0; i < 96; i++) { 
    if (currentMillis - previousMillisStim[i] >= timeON[i]){ // checking timer
      if (state[i] == 1){ // checking if well is ON
        setBlue(i, 0);  
     
        state[i] = 0; // indicates that well light is OFF
        previousMillisStim[i] = currentMillis; 
      }
    }
  }
  tlc.write();
}

// *** CALIBRATION PROTOCOL *** //

void calibrate(){ 
  for (int i = 0; i < 96; i++) {//
    setOD(i, 500);
    setBlue(i, 0);
    tlc.write();
    tlc.write();
    
    Serial.println("odon");
    String r = Serial.readStringUntil(';');
    while (r != "nextO"){
      r = Serial.readStringUntil(';');
    }
    setOD(i,0);
    tlc.write();       
  }
  
  Serial.end();  // SHUTDOWN PLATE
  while (true) { // Experiment Complete 
  }
}

// *** OPTICAL DENSITY READING *** //

void OpticalDensity(){
  int cal = Serial.readStringUntil(';').toInt(); // save calibrated red LED intentisty for first well
  for (int i = 0; i < 96; i++) {
    setBlue(i,0); // turn all blue LEDs OFF 
  }  
  tlc.write();
  
  // Reading loop
  for (int i = 0; i < 96; i++) {
    if (all_wells.charAt(i) == '1'){
      setOD(i, cal); // turn single red LED ON
      tlc.write();
      Serial.println(cal);
      Serial.println("odon");
      String r = Serial.readStringUntil(';');
      while (r != "nextO"){
        r = Serial.readStringUntil(';');
      }
      cal = Serial.readStringUntil(';').toInt(); // save calibrated red LED intensity for next well
      setOD(i,0); // turn singlered LED OFF
      tlc.write();       
    }
  }  
}

// *** RESUME STIMULATION PATTERN AFTER OD READING *** //

void resumeStim_OD(){
  // Turn red LEDs OFF
  for (int i = 0; i < 96; i++) {
        setOD(i, 0); // turn single red LED OFF
   }

  // Resume stimulation LEDs
  for (int i = 0; i < 96; i++) { 
    if (state[i] == 1){ // checking if stimulation LED is meant to be ON 
       setBlue(i,intensity[i]);
    }
  }
  tlc.write();
  tlc.write();
}

// *** FLUORESCENCE READING *** 

void Fluorescence(){
  for (int i = 0; i < 96; i++) { // turn all LEDs OFF
    setBlue(i,0);
  }
  tlc.write();
  fpSwitch = 1; // Indicate fluorescence is being read
  String r =  Serial.readStringUntil(';');
  while (r != "done"){ // wait until fluorescence is complete
    r =  Serial.readStringUntil(';');
  }
 
}

// *** RESUME STIMULATION PATTERN AFTER FLUOR READING ***

void resumeStim_Fluor(){
  if(fpSwitch == 1){
      fpSwitch = 0; // indicates fluorescence is no longer reading
      for (int i = 0; i < 96; i++) { 
        if (state[i] == 1){ // checking if stimulation LED is meant to be ON
          setBlue(i,intensity[i]); //
        }
      }
  tlc.write();
  }
}

// *** NEW STIMULATION PATTERN FEEDBACK *** //
// python needs to send "number of wells; x; intensity; timeON; timeOFF; ...x_n; intensity_n; timeON_n; timeOFF_n" 

void new_stimulation(){
  int well_count = Serial.readStringUntil(';').toInt(); // number of wells who's settings are changing
  for (int i = 0; i < well_count; i++){
      int w = Serial.readStringUntil(';').toInt(); // index of well
      intensity[w] = Serial.readStringUntil(';').toInt(); // LED intensity
      // timeON[w] = Serial.readStringUntil(';').toInt(); // LED ON duration
      // timeOFF[w] = Serial.readStringUntil(';').toInt(); // LED OFF duration
    }
}

// *** SHUTDOWN *** //

void endComm(){
  for (int i = 0; i < 96; i++){
    setBlue(i,0);
    setOD(i,0);
  }
  tlc.write();
  tlc.write();
  Serial.end();
  while (true) { // Experiment Complete
  }
}

void setBlue(uint16_t well, uint16_t bright){
  //This is how Lukasz encoded each well to a channel number
  //well is a number ranging from 0 to 95 (for 96 total wells)
  //The formula well/12+8*(well%12) gives the driver channel controlling
  //the blue LED at that well
  uint16_t bluePosition = (uint16_t)((int)(well/12) + 8*(11-well%12));
  tlc.setPWM(bluePosition, bright);   //Set Blue

}

void setRed(uint16_t well, uint16_t bright){
  //The formula (well/12) + 8*(well%12)+96) gives the driver channel 
  //controlling the red LED at that well
  //uint16_t redPosition = (uint16_t)((int)(well/12) + 8*(well%12)+96); 
  uint16_t redPosition = (uint16_t)((int)(well/12) + 8*(11-(well%12))+96);  
  tlc.setPWM(redPosition, (bright));   //Set Red
}

void setOD(uint16_t well, uint16_t bright){
  //The formula (well/12) + 8*(well%12)+96) gives the driver channel 
  //controlling the red LED at that well
    uint16_t fBluePosition = (uint16_t)((int)(well/12)*12 +(11-(well%12))+192);
    tlc.setPWM(fBluePosition, bright); 

}


// *** ALL LED CONTROL *** //

//This function turns on all 3 LEDs at that position
void setAll(uint16_t well, uint16_t bright){
  setBlue(well, bright);
  setOD(well, bright);
}

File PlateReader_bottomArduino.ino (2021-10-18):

  /* PLATE READER TESTING */

/* ----------------DRIVER SETUP------------- */
#include "Adafruit_TLC5947.h"

//Sets up arduino pins for drivers
const uint8_t NUM_TLC5974 = 8; 
const uint8_t data  = 13;
const uint8_t clock = 5;
const uint8_t latch = 4;

Adafruit_TLC5947 tlc = Adafruit_TLC5947(NUM_TLC5974, clock, data, latch); //creates LED driver object

const int UVs[24] = {0, 1, 2, 3, 4, 5, 6, 7, 8, 9, 10, 11, 23, 22, 21, 20, 12, 13, 14, 15, 16, 17, 18, 19};

const int Blues[24] = {0, 1, 2, 3, 4, 5, 6, 7, 8, 9, 10, 11, 22, 23, 21, 20, 19, 18, 17, 16, 15, 14, 13, 12};


/* ---------------MULTIPLEXER SETUP--------------- */
//Sets up arduino pins for multiplexer

int S[4] = {A1, A2, A3, A4};
int CS[6] = {7, 8, 9, 10, 11, 12};
int INPIN = A0;

/* ----------------VARIABLE SETUP ----------------- */
// Protocol inputs
String ledType1;  
String readNum1;  //Number of photodiode readings for Red LED
int od_readNum;
String stringWells1;
String all_wells;
String ledType2;      //LED type read from Python
String readNum2;      //Number of photodiode readings for UV LED
int fp_readNum;             
String protocol;


/* ----------------SETUP-------------- */
void setup() {
  //DRIVER SETUP
  tlc.begin();                //Initiate driver library
  Serial.begin(9600); //Begin serial monitor

  for (int x = 0; x < 4; x++) {
    pinMode(S[x], OUTPUT); // multiplexer outputs
  }
  
  for (int x = 0; x < 6; x++) {
    pinMode(CS[x], OUTPUT); // chip select outputs
  }
  pinMode(A0, INPUT);
  for (int i=0; i<96; i++) {
    SetBlues(i, 0); // sets blue LEDs to OFF
    SetUVs(i, 0); // sets UV LEDs to OFF 
    tlc.write();
  }

  //Establish serial connection between Python and Arduino
  while (Serial.available() == 0) {
    //Wait for connection
  }
  while (Serial.available() > 0) {
    Serial.read();
  }
  
  //Serial.println(Serial.readStringUntil(';'));
  while (Serial.readStringUntil(';') != "start"){
    //Wait
  }
  while (Serial.available() == 0) {
    //Wait for connection;
  }
  String r = Serial.readStringUntil(';');
  if (r == "calibrate"){
    calibrate();
  }
  
  
  // Read serial data from Python
  // Optical Density Reading Protocol
  ledType1 = Serial.readStringUntil(';'); //  O 
  readNum1 = Serial.readStringUntil(';'); // number of photodiode readings for Red LED
  stringWells1 = Serial.readStringUntil(';'); //  String of 96 char 0/1 numbers [same for Fluorescence reading]

  // Fluorescence Reading Protocol
  ledType2 = Serial.readStringUntil(';'); //  F
  readNum2 = Serial.readStringUntil(';'); // number of photodiode readings for UV LED
  

  //Serial.println("Received"); //Notify Python that it has been received

  // Save optical density protocol variable
  if (ledType1 == "O") { //  Saves OD protocol variables 
    od_readNum = readNum1.toInt();
    all_wells = stringWells1; 
  }
 // Save fluorescence protocol variable
  if (ledType2 == "F") {
    fp_readNum = readNum2.toInt(); 
  }
 }

void loop() {
  
  protocol = Serial.readStringUntil(';'); // Constantly waiting to read from Pi
  // protocol = Serial.readString(); // alternative 

  
  if (protocol == "F"){ // FLUORESCENCE READING 
    Fluorescence();
  }  
  
  if (protocol == "O") {  // OPTICAL DENSITY READING 
    OpticalDensity();
  }


  if (protocol == "shutdown"){  // SHUTDOWN EXPERIMENT
    endComm();
  }
} 

// *** CALIBRATION PROTOCOL **** //

void calibrate(){
  for (int i = 0; i < 96; i++) {
     String r = Serial.readStringUntil(';');
     while (r != "readO") {
          //wait
        r = Serial.readStringUntil(';');
      }

      SetWell(i); // connects multiplexer and pin
      delay(100); 
        
      //Take photodiode readings and send to Pi 
      Serial.println(".");
        
        double sum = 0;
        for (int q = 0; q < 10; q++){
           sum = sum + analogRead(INPIN);    
        }
        String readout = String(round(sum/10)) + "D";
        Serial.println(readout); // sends OD reading to Pi
      }
    Serial.println("*");    // Signals end of OD readings
    Serial.end();
    while (true) {
      // Experiment Complete
    }
}


//  *** FLUORESCENCE READING  PROTOCOL *** //

void Fluorescence(){ 
  for (int i = 0; i < all_wells.length(); i++) {
    if (all_wells.charAt(i) == '1'){  // selecting well that is part of protocol
    
      //Turn on UV LED
      SetUVs(i, 4095);
      tlc.write(); 

      SetWell(i); // connects multiplexer and pin
      delay(100); 
      
      //Take photodiode readings and send to Pi 
      Serial.println("#");
      double sum = 0;
      for(int j = 0; j < fp_readNum; j++){ // reads x number of readings
        sum = sum + analogRead(INPIN);  // sends UV reading to Pi
      }
      Serial.println(round(sum/fp_readNum)); // sends FP reading to Pi
      
      //Turn off UV LED
      SetUVs(i, 0);
      tlc.write();
    }
  }
  Serial.println("!");    // Signals end of Fluorescence readings
  Serial.flush();
}

//  *** OPTICAL DENSITY READING  PROTOCOL *** //

void OpticalDensity(){
  for (int i = 0; i < 96; i++) {
      if (all_wells.charAt(i) == '1'){

        String r = Serial.readStringUntil(';');
        while (r != "readO") {
          //wait
          r = Serial.readStringUntil(';');
        }

        SetWell(i); // connects multiplexer and pin
        delay(100);
        
        //Take photodiode readings and send to Pi 
        Serial.println("."); // signal beginning of well readings
        
        double sum = 0;
        for (int q = 0; q < od_readNum; q++){
           sum = sum + analogRead(INPIN); // takes the specified number of readings and sums them    
        }
        String readout = String(round(sum/od_readNum)) + "D"; // gets average reading for indivudal well; 
        Serial.println(readout); // sends raw OD reading to computer
      }
    }
    Serial.println("*");    // Signals end of OD readings
  
}

//  *** SHUTDOWN PROTOCOL *** //

void endComm(){
  Serial.end();
  for (int i = 0; i < 96; i++){
    SetUVs(i, 0);     //Turn off UV LED
    tlc.write();
    while (true) { // Experiment Complete
    }
  }
}

// *** SELECT MULTIPLEXER AND PIN *** //
void SetWell (int Well) {
  int VerticalWell = 8*(Well%12)+Well/12;
  int SetPin = VerticalWell;
  if ((VerticalWell/8)%2==1) {
    SetPin = VerticalWell+(8-VerticalWell)*2+7;
  }

  //CSselect function followed by pinselect in the same function
  for (int i=0; i<6; i++){
    digitalWrite(CS[i], HIGH);
  }
  delay(100);
  int CSselect = CS[VerticalWell/16];
  digitalWrite(CSselect, LOW);
  for (int x = 0; x<4; x++){
    byte state = bitRead(SetPin, x);
    digitalWrite(S[x], state);
  }
  delay(100);
}

// *** CONTROLS BLUE LEDS *** //
void SetBlues(int Well, int Int) {
  int VerticalWell = 8*(Well%12)+Well/12;
  int BluePin = Blues[VerticalWell%24]+24*(VerticalWell/24)+96;
  tlc.setPWM(BluePin, Int);
}
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
